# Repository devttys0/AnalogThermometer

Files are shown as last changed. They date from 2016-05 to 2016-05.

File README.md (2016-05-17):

Analog Thermometer
===================

A small, simple, low power circuit that turns practically any analog ammeter into an attractive thermometer, displaying temperatures from 0-70C with a typical accuracy of +-1 degree celcius.

  * One inch square PCB size
  * Low cost (single quantity [components](./digikey_bom.csv): $7, OSHPark PCB: $5)
  * Runs from a single 2.5-5.5V supply, typical current consumption <15uA (plus the analog ammeter's current requirements)
  * Easily adapted to work with nearly any ammeter by changing a single resistor, and/or adjusting a potentiometer

3D rendering of the PCB design:

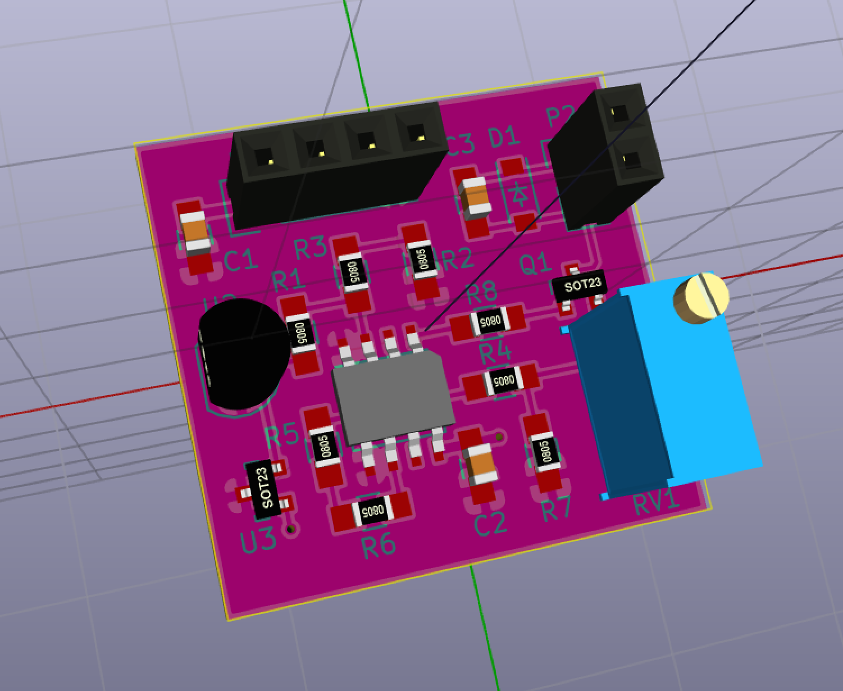
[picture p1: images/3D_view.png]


A Cole DC ammeter displaying the lab temperature of 20 degrees Celcius:

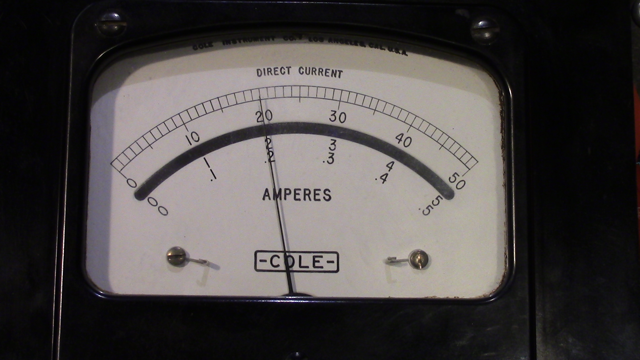
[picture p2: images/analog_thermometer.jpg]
Cole Ammeter Displaying Lab Temperature


Circuit Description
===================

The AnalogThermometer circuit is based around a Microchip MCP9700A temperature sensor. An LTC1541 op-amp is used as a differential amplifier to remove the 500mV offset voltage from the MCP9700A's output voltage. Finally, the differential amplifier controls a simple NPN current sink, whose current varies linearly with temperature; this drives the analog ammeter with a current that is proportional to the ambient temperature.

Circuit Construction
====================

Circuit construction is largely the same for any analog meter, with only two design questions that must be answered:

1. Do you want the MCP9700A temperature sensor to be a surface mount or a through-hole component?
2. What resistor value should be used for resistor R7 in order to accurately display the temperature on your analog meter?

Surface mount or through-hole?
------------------------------

Provisions have been made on the PCB for both the through-hole and surface mount versions of the MCP9700A temperature sensor. There is no technical advantage one way or the other, so the decision of which one to use is primarily determined by physical constraints / personal preference.

In the schematic and on the PCB, U2 is the through-hole version (TO-92 package) and U3 is the surface mount version (SOT-23). **Populate either U2 or U3, but not both!**

What value resistor do I use for R7?
------------------------------------

Different analog meters require different amounts of current for full-scale deflection of the meter's needle. The selection/adjustment of resistors R7/RV1 directly determines how much current is put through the analog meter for each degree of temperature change.

The easy way to set the correct amount of current is to simply not populate resistor R7 at all and adjust the potentiometer RV1 until the analog meter reads the correct temperature. If you choose this option, that's all you need to do and your work is done. The downsides to this however is that it requires fiddly adjustments, and will inevitably be less accurate than selecting a fixed resistor of the correct value.

The preferred method is to leave the potentiometer RV1 unpopulated and calculate exactly the correct amount of resistance required. Resistor R7 can then be populated with a fixed resistor of the appropriate value.

The amount of current that your analog meter requires is determined by the full-scale deflection current of your meter, and the scale printed on the meter's faceplate. Alan, W2AEW, has made some excellent videos on [finding the full-scale deflection current of a meter](https://www.youtube.com/watch?v=wbRx5cQZ8Ts&t=3m22s), as well as [printing custom scales for the face
plate](https://www.youtube.com/watch?v=wbRx5cQZ8Ts&t=13m09s). **His videos are highly recommended if you are not familiar with analog meters**.

Here is a simple example. This particular meter was manufactured with a scale of 0-50uA on the faceplate, which is ideal for our application as the temperature in degrees celcius can be read directly from the existing scale:

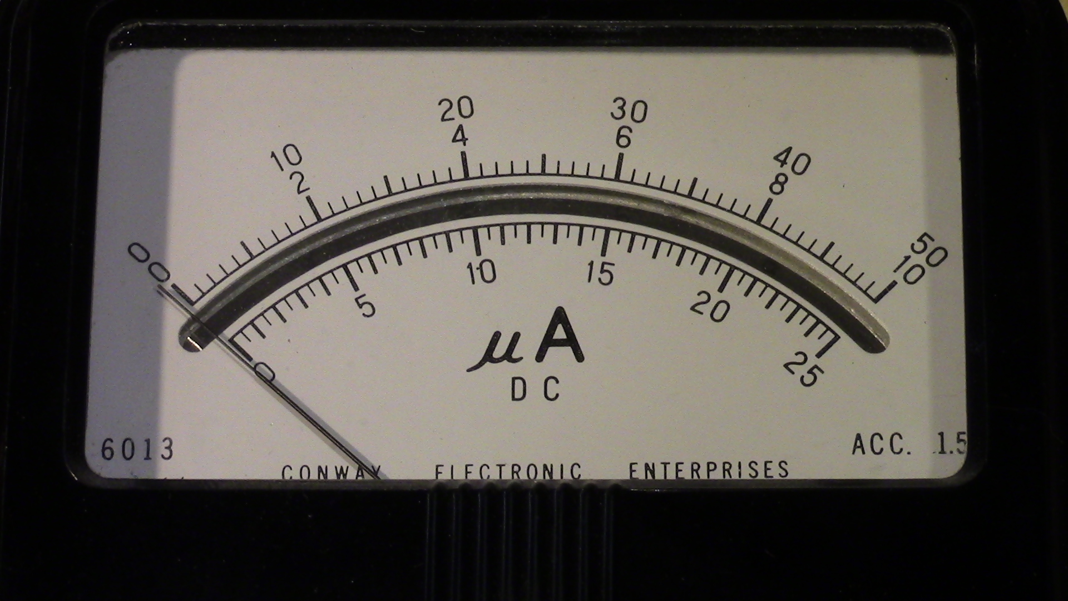
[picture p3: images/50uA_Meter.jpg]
Exemplar ammeter


Having settled on a scale of 0-50, all that is left is to determine how much current is required to deflect the needle full-scale. Some analog meters will have this value conveniently printed on them:

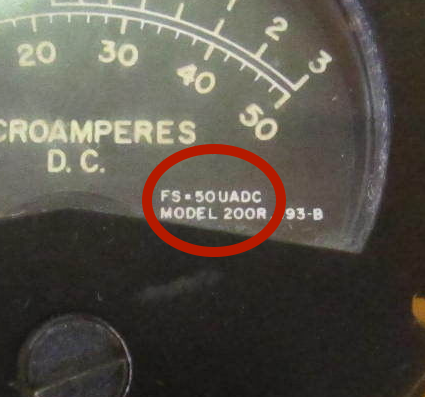
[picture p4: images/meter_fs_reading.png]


The text `FS=50UADC` on this meter tells us that 50uA of direct current will deflect the meter to its full-scale position.

Unfortunately, the analog meter used in our example does not have this information printed on it, but it is easy to experimentally determine the full-scale current by placing a current meter in series between an adjustable voltage power supply and the analog meter. If you don't have an adjustable voltage source, a fixed voltage source with a variable resistor will work just as well:

Setup to Measure Full Scale Current

Simply increase the power supply voltage until the needle is deflected full-scale, then read the current measured by the current meter. In this case, it is 25uA:

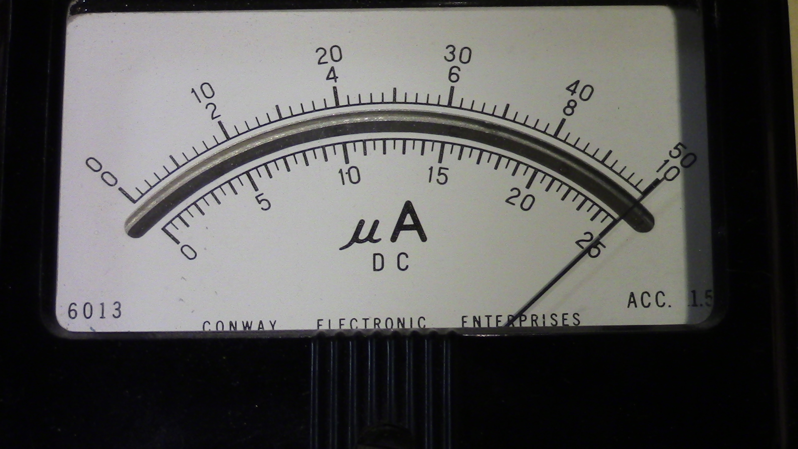
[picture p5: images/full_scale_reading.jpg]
Meter Needle At Full Scale


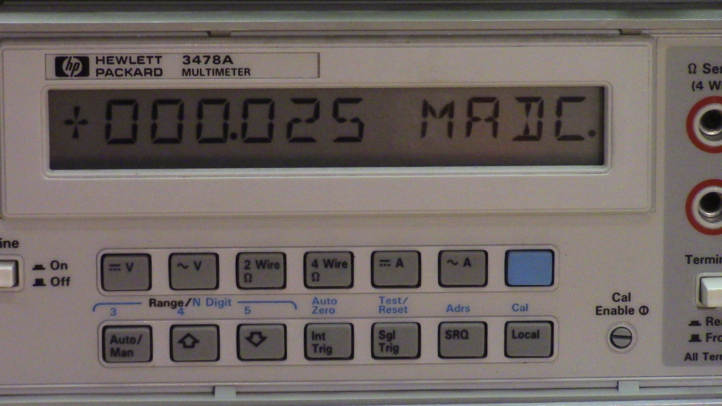
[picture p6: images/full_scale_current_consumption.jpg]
Current Required to Drive Meter to Full Scale


Since our scale ranges from 0 to 50 degrees, and the current required for a full-scale reading of 50 degrees is 25uA, we can calculate how much current is required to move the needle by one degree on our 0-50 scale:

```
25uA / 50 = 0.5uA
```

So we need the current to increase by 0.5uA for a one degree increase in temperature. The AnalogThermometer circuit increases the voltage across resistor R7 by 10mV for a one degree celcius increase, so ohm's law tells us that resistor R7 must be:

```
10mV / 0.5uA = 20,000
```

A 20k ohm resistor can be used for resistor R7. Resistors with tolerances of 1% or better are recommended.

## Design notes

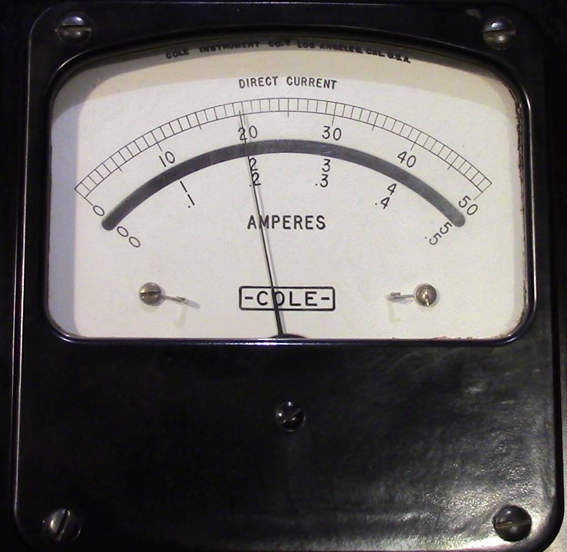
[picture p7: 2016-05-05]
images/analog_thermometer.png

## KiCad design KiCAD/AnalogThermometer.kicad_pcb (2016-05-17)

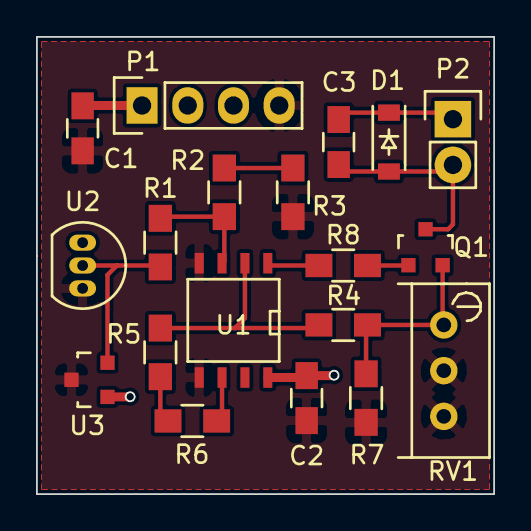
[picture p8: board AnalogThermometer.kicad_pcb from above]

Board: 2 copper layers, 25.4 x 25.4 mm, 19 parts (0 on the bottom side), 12 nets.

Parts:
C1, C2, C3: 0.1uF; C_0805_HandSoldering
D1: 1N4148; SOD-123
P1: Power; Socket_Strip_Straight_1x04
P2: uA; Socket_Strip_Straight_1x02
Q1: MMBT3904; SOT-23
R1, R4: 1M; R_0805_HandSoldering
R2, R5: 2.2M; R_0805_HandSoldering
R3, R6: 200k; R_0805_HandSoldering
R7: 49.9k; R_0805_HandSoldering
R8: 100; R_0805_HandSoldering
RV1: 100k; Potentiometer_Bourns_3296W_3-8Zoll_Inline_ScrewUp
U1: LTC1541; SOIC-8-N
U2: MCP9700A; TO-92_Inline_Narrow_Oval
U3: MCP9700AT; SOT-23

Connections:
+5V: C1.2, C2.2, C3.2, D1.1, P1.1, P2.1, U1.8, U2.1, U3.1
GND: C1.1, C2.1, P1.4, R3.1, R7.1, RV1.2, RV1.3, U1.4, U1.5, U2.3, U3.3
unnamed: C3.1, D1.2, P2.2, Q1.3
unnamed: Q1.1, R8.1
unnamed: Q1.2, R4.1, R7.2, RV1.1
unnamed: R1.1, R2.2, U1.3
unnamed: R1.2, U2.2, U3.2
unnamed: R2.1, R3.2
unnamed: R4.2, R5.2, U1.2
unnamed: R5.1, R6.2
unnamed: R6.1, U1.6
unnamed: R8.2, U1.1

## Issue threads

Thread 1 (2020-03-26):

getting the schematic to open in KiCad 5.x

twobob, 2020-03-26:
It would seem that there is some manual work required in doing this.  The format has changed?

Ultimately I was hoping to create a CPL for this :)

Great project, Love your videos and website (as was)  it's still on wayback by the way

twobob, 2020-03-26:
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
okay think that was everything. Just seems to be some new taxonomy and a few slightly different codes. First go ever at this so... yeah.

twobob, 2020-03-26:
Perhaps I should ask a better question. Was there a .pos file for this? Many thanks.

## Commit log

2016-04-12 Initial project check in
    [AnalogThermometer.kicad_pcb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]
2016-05-04 Updated to rev 1.2
    [AnalogThermometer-B.Cu.gbr, AnalogThermometer-B.Mask.gbr, AnalogThermometer-B.SilkS.gbr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]
2016-05-15 Directory re-structure
    [AnalogThermometer.kicad_pcb, AnalogThermometer.sch]
2016-05-15 Minor update
    [digikey_bom.csv]
2016-05-17 Updated board and gerbers to be 1x1 inch
    [AnalogThermometer-B.Cu.gbr, AnalogThermometer-B.Mask.gbr, AnalogThermometer-B.SilkS.gbr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]
